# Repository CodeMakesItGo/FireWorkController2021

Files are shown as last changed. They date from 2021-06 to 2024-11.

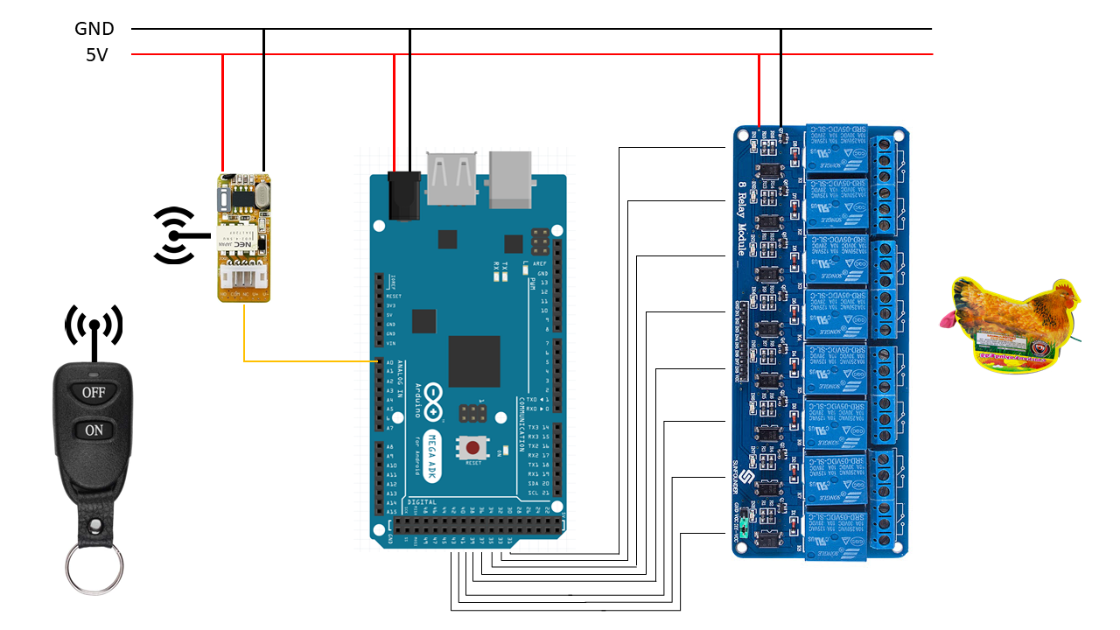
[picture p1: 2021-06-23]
General Idea.PNG

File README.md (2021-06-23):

# FireWork Controller 2021

The build for this firework controller is featured here:
https://youtu.be/X29aCa7rGqE

This project is using the Arduino Mega and 32 relays to individually trigger fireworks.
The timing of the fireworks are in 100ms increments. 

There is not much to this project, as you can see, the program is very simple. 
After setting the time for each output, start the show by setting the analog input 0 high. 
The Arduino will trigger the output and keep it on for a set amount of time. The default is 1 second.
This gives the fuse enough time to ignite. Although the e-matches ignite very fast in my experience.

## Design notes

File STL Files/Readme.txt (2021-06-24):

You will need to print the following:
1 x FireWorkControllerBase
1 x MegaMount
1 x MicroMount
6 x Relay Brace
2 x Relay Mount

Option cover for the controller:
1 x HardHat

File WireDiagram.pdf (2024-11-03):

| VC | GND | RelayNO-A | RelayNO-B | GND | VC | IN-1 | IN-2 | IN-3 | IN-4 | IN-5 | IN-6 | IN-7 | IN-8 | VC | GND | VC | GND
GND | | x | | | | | | | | | | | | | | x
5V | x | | | | | x | | | | | | | | | x
A0 | | | | x
22 | | | | | | | 1
23 | | | | | | | | 1
24 | | | | | | | | | 1
25 | | | | | | | | | | 1
26 | | | | | | | | | | | 1
27 | | | | | | | | | | | | 1
28 | | | | | | | | | | | | | 1
29 | | | | | | | | | | | | | | 1
30 | | | | | | | 2
31 | | | | | | | | 2
32 | | | | | | | | | 2
33 | | | | | | | | | | 2
34 | | | | | | | | | | | 2
35 | | | | | | | | | | | | 2
36 | | | | | | | | | | | | | 2
37 | | | | | | | | | | | | | | 2
38 | | | | | | | 3
39 | | | | | | | | 3
40 | | | | | | | | | 3
41 | | | | | | | | | | 3
42 | | | | | | | | | | | 3
43 | | | | | | | | | | | | 3
44 | | | | | | | | | | | | | 3
45 | | | | | | | | | | | | | | 3
46 | | | | | | | 4
47 | | | | | | | | 4
48 | | | | | | | | | 4
49 | | | | | | | | | | 4
50 | | | | | | | | | | | 4
51 | | | | | | | | | | | | 4
52 | | | | | | | | | | | | | 4
53 | | | | | | | | | | | | | | 4
Vin (+) | | | x
Vout(+) | | | | | | x | | | | | | | | | | | x
Vin (-)
Vout (-) | | | | | x | | | | | | | | | | | | | x
TRIG | | | | x
GND

FET Trigger Switch

## FireWork Controller 2021

Remote Switch | 8 Array Relays [1-4]

Arduino Mega 2560

Power LED | Disco LED

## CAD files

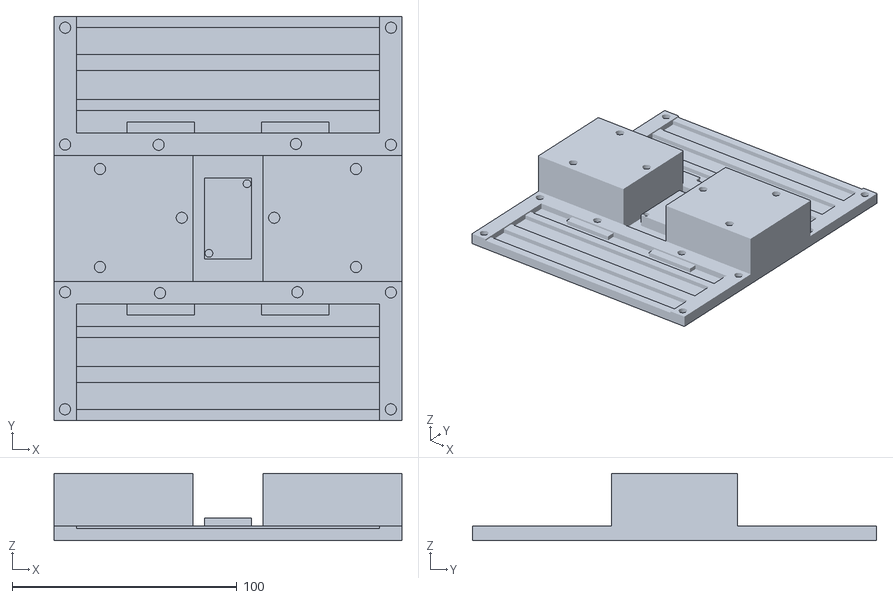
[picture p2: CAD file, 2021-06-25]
STL Files/FireWorkcontrollerBase.stl
155.0 x 180.0 x 30.0

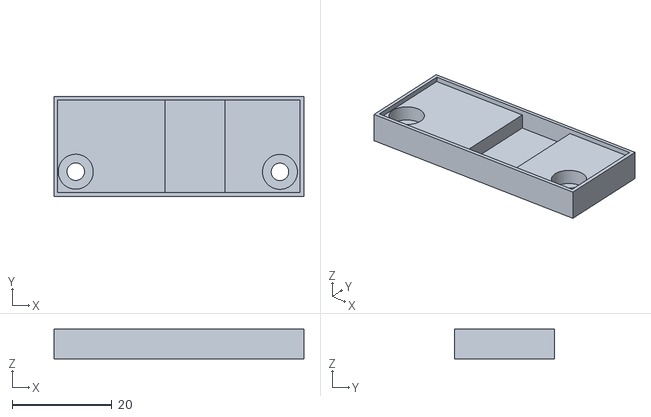
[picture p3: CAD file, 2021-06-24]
STL Files/ExtraMount.stl
50.0 x 20.0 x 6.00

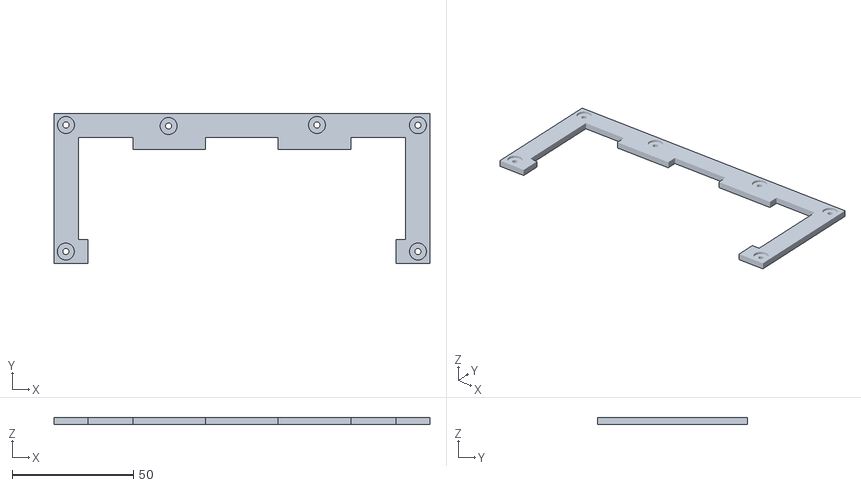
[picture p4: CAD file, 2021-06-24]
STL Files/Relay Brace.stl
155.0 x 62.0 x 3.00

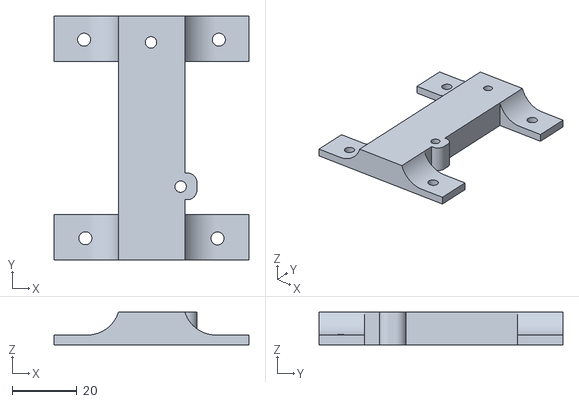
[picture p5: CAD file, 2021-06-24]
STL Files/MicroMount.stl
60.0 x 75.0 x 10.0

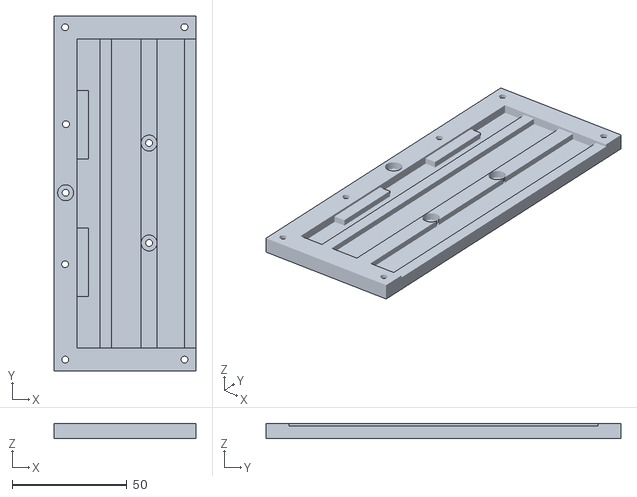
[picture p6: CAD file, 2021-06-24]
STL Files/Relay Mount.stl
62.0 x 155.0 x 6.50

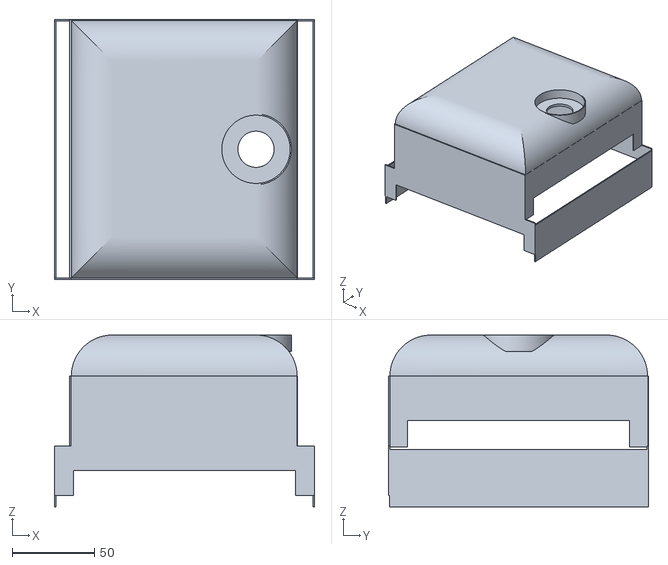
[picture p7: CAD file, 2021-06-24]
STL Files/HardHat.stl
158.0 x 158.0 x 104.5

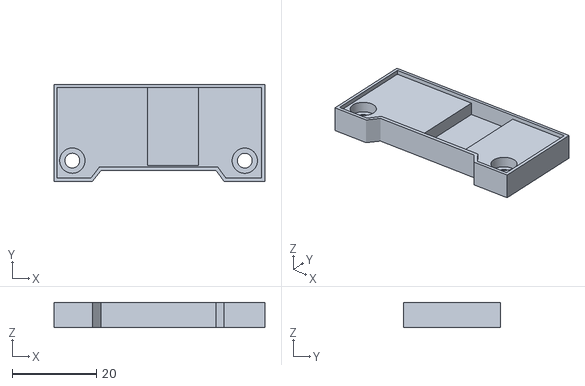
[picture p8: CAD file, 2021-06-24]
STL Files/ExtraMountGap.stl
50.0 x 23.0 x 6.00

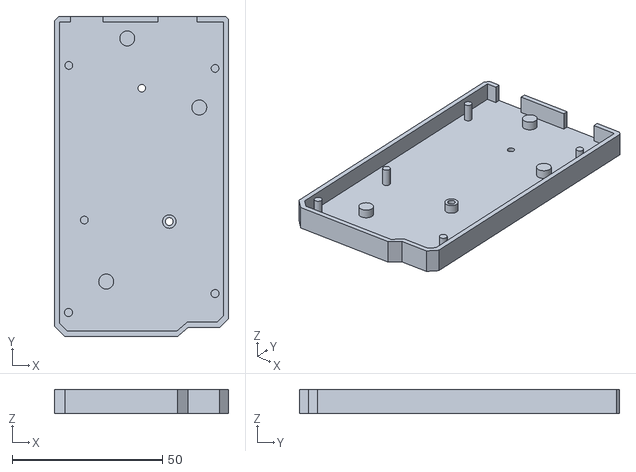
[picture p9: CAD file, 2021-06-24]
STL Files/MegaMount.stl
58.1 x 106.6 x 8.00

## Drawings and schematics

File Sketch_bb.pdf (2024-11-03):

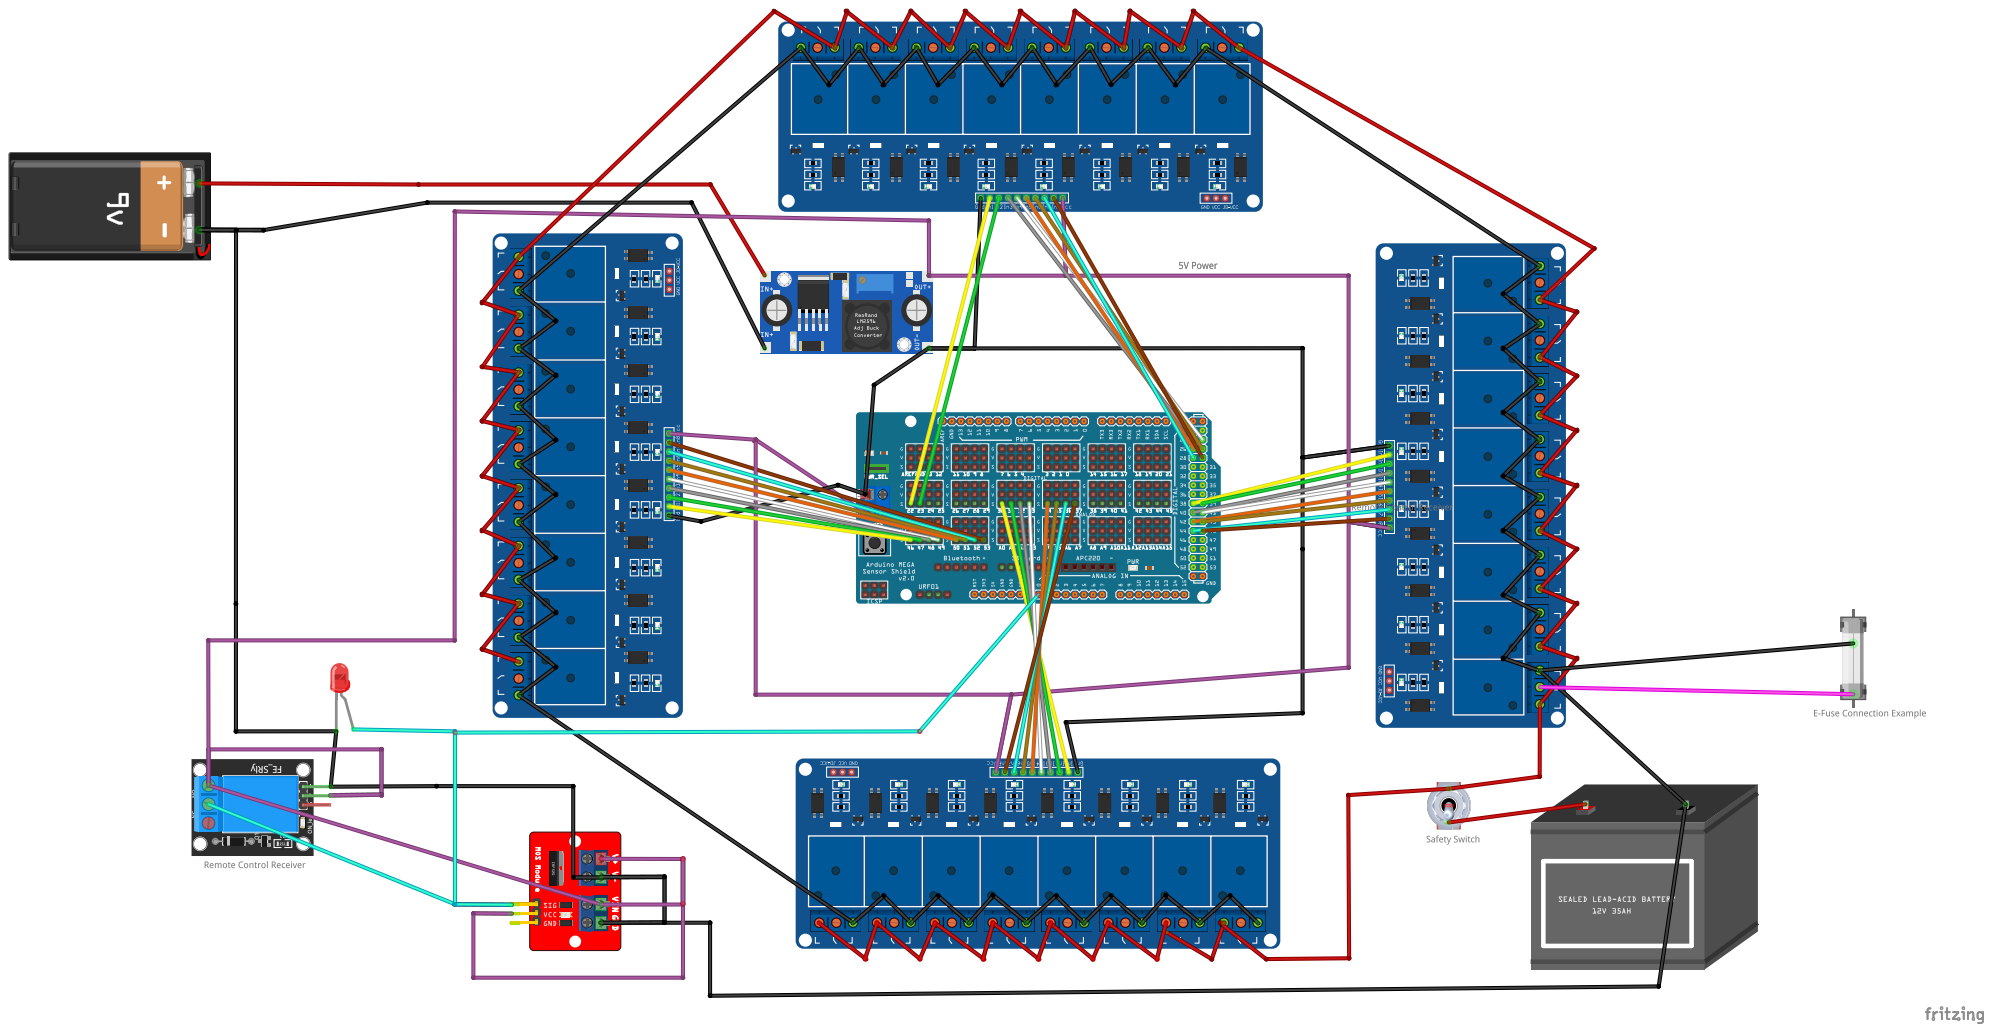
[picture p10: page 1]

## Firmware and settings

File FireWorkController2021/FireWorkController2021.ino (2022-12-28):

//Defines for hardware setup
#define START_PIN    A0  // Feedback from the remote on/off switch
#define NUM_OUTPUTS  32  // will never change for this board

//Defines for application
#define UPDATES_PER_SECOND 10     // 10Hz
#define DISABLED -1               // Set this as the output time to disable it
#define STAY_ON_DURATION_MS 1000  // one second stay on time

// The global timer used to play the show
unsigned long timer = 0;  

// Memory structure to store the pin and output ignite time
typedef struct 
{
  int pin;
  long igniteTime;
}output;

// All 32 outputs
// Set the time in 100ms increments (because this runs at 10Hz)
// The pin is the digital output, should not be changed
// This time is when you want the firework to ignite
// Set time to 'DISABLE' for any outputs that are not used 
output outputs[NUM_OUTPUTS] = 
{
 // PIN, Time
   {22, 500}, // OUTPUT 1
   {23, 1000}, // OUTPUT 2
   {24, 1500}, // OUTPUT 3
   {25, 2000}, // OUTPUT 4
   {26, 2500}, // OUTPUT 5
   {27, 3000}, // OUTPUT 6
   {28, 3500}, // OUTPUT 7
   {29, 4000}, // OUTPUT 8
   {30, 4500}, // OUTPUT 9
   {31, 5000}, // OUTPUT 10
   {32, 5500}, // OUTPUT 11
   {33, 6000}, // OUTPUT 12
   {34, 6500}, // OUTPUT 13
   {35, 7000}, // OUTPUT 14
   {36, 7500}, // OUTPUT 15
   {37, 8000}, // OUTPUT 16
   {38, 8500}, // OUTPUT 17
   {39, 9000}, // OUTPUT 18
   {40, 9500}, // OUTPUT 19
   {41, 10000}, // OUTPUT 20
   {42, 10500}, // OUTPUT 21
   {43, 11000}, // OUTPUT 22
   {44, 11500}, // OUTPUT 23
   {45, 12000}, // OUTPUT 24
   {46, 12500}, // OUTPUT 25
   {47, 13000}, // OUTPUT 26
   {48, 13500}, // OUTPUT 27
   {49, 14000}, // OUTPUT 28
   {50, 14500}, // OUTPUT 29
   {51, 15000}, // OUTPUT 30
   {52, 15500}, // OUTPUT 31
   {53, 16000}  // OUTPUT 32
};

//comment out the next line if your relays are active LOW
#define ACTIVE_HIGH

#ifdef ACTIVE_HIGH
#define ACTIVE HIGH
#define INACTIVE LOW
#else
#define ACTIVE LOW
#define INACTIVE HIGH
#endif

// Turn off all outputs
void allOff()
{
  //Turn off all outputs
  for( int i = 0; i < NUM_OUTPUTS; i++) 
  {
      digitalWrite(outputs[i].pin, INACTIVE);
  }
}

// Cycle through the array and turn on or off the outputs 
void playShow()
{
  for( int i = 0; i < NUM_OUTPUTS; i++) 
  {  
    if( outputs[i].igniteTime != DISABLED &&
        timer >= (unsigned long)outputs[i].igniteTime && 
        timer < (unsigned long)(outputs[i].igniteTime + STAY_ON_DURATION_MS) )
    {
      //Check if it is currently off
       if(digitalRead(outputs[i].pin) == INACTIVE)
       {
        Serial.print("Output ");
        Serial.print(outputs[i].pin);
        Serial.println(" is On");
       }
       
       //Turn output on
       digitalWrite(outputs[i].pin, ACTIVE);
    }
    else
    {
      //Check if it is currently on
      if(digitalRead(outputs[i].pin) == ACTIVE)
       {
        Serial.print("Output ");
        Serial.print(outputs[i].pin);
        Serial.println(" is Off");
       }
       
      //Turn output off
      digitalWrite(outputs[i].pin, INACTIVE);
    }
  }
}

// setup serial and digital outputs
void setup() 
{
  Serial.begin(9600);
  
  for( int i = 0; i < NUM_OUTPUTS; i++) 
  {
      pinMode(outputs[i].pin, OUTPUT);
      digitalWrite(outputs[i].pin, INACTIVE);
  }

  // This is an analog input pin
  pinMode(START_PIN, INPUT);

  Serial.println("Ready");
}

// Run loop at a fixed frequency
void loop() 
{
  static unsigned long current_time = millis();
  static const int interval = 1000 / UPDATES_PER_SECOND;

  // cycle set to 10Hz
  if(millis() > current_time + interval)
  {
    // Reset our frequency timer
    current_time = millis();

    
    if(digitalRead(START_PIN) == HIGH)
    {
      if(timer == 0)
      {
        Serial.println("Show has started.");
      }
      
      // Set next cycle time
      timer += interval; 

      // show time!
      playShow();
    }
    else
    {
      if(timer != 0)
      {
        Serial.println("Show has stopped.");
      }

      // turn all the relays off
      allOff();

      // reset our timer to restart the show
      timer = 0;  
    }
  }
}

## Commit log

2021-06-25 Fixed error in STL
    [FireWorkcontrollerBase.stl]
2022-04-21 Update WireDiagram.pdf
    fix mistake in VC
2022-10-31 Added fritzing diagram
    [Sketch.fzz]
2022-12-28 Updated to active high relays
    Comment out line 63 if your relays are active low
2024-11-03 updated diagrams
    [Sketch.fzz]
